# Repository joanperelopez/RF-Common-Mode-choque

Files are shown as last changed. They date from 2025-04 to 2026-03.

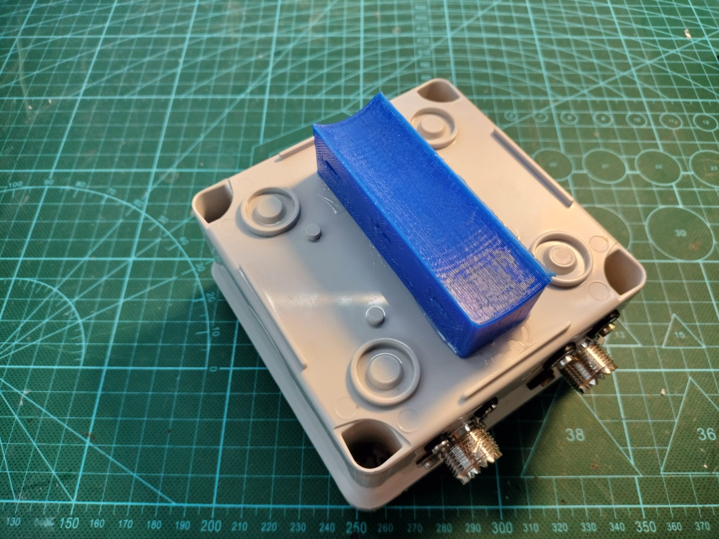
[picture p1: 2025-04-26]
IMAGES/WhatsApp Image 2025-04-26 at 18.15.16-2.jpeg

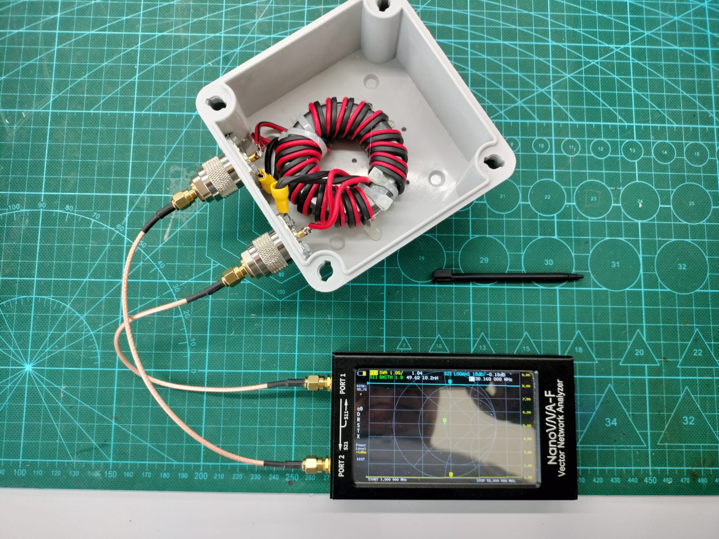
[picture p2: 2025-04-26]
IMAGES/WhatsApp Image 2025-04-26 at 18.15.17.jpeg

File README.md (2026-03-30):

# RF Common-Mode choque for outdoor use

This is the construction project of a common-mode filter designed to be installed on the mast, as close as possible to the antenna. It is housed inside an IP55-rated protective box with SO-239 connectors.
WhatsApp Image 2025-04-26 at 18 15 16
Common-mode choke. 10 turns of 2x1mm bifilar wire on each side of a 240-43 ferrite, as shown in the photograph.

WhatsApp Image 2025-04-26 at 18 15 17-2
Installation inside a weatherproof plastic box with IP55 protection. The connectors are SO-239, 50 Ohm.
Between the plastic box and the connectors, I applied white silicone.

The red wires at each end are soldered together to the center terminal of the corresponding SO-239 connector. The black wires at each end are also soldered together to the shell of the SO-239 connector.
Once all the connections were soldered, I applied a generous amount of white silicone to prevent moisture from reaching the connections.
I added rubber washers to the connector screws to prevent water from entering.

Secure the ferrite to the box using hot glue.

### Let’s see how it performs with the NanoVNA

WhatsApp Image 2025-04-26 at 18 15 15-2
The impedance is correctly maintained at 50 Ohms in the range of 1.8 MHz to 52 MHz.

WhatsApp Image 2025-04-26 at 18 15 15
The common-mode attenuation remains below -30 dBm. In the 20-meter band, it reaches -36 dBm.

WhatsApp Image 2025-04-26 at 18 15 17
The insertion loss is -0.1 dBm.

### We make the final touches
WhatsApp Image 2025-04-26 at 18 15 14
The completed choke with the placement of the informational label.

WhatsApp Image 2025-04-26 at 18 15 16-2
Installation of a bracket to allow it to be mounted on the antenna mast. It is attached to the box using a two-component adhesive. 
You can download it from the MECHANICAL folder.

WhatsApp Image 2025-04-26 at 18 15 14-2
Only three cable ties are needed for securing it to the antenna mast.

### RF choque version two
WhatsApp Image 2026-03-30 at 12 33 22
I've made another version of the RF choke, as I was experiencing some RF in the radio room. It consists of 14 turns of RG58 coaxial cable, as shown in the photo. Made with a toroidal core 240-31.

WhatsApp Image 2026-03-30 at 12 33 22 (1)
The impedance remains very stable: 49,9 Ohm at 100Khz. (ROE 1.0)  49,5 Ohm at 52 Mhz. (ROE 1.01)  47,6 Ohm at 100Mhz. (ROE 1.07).

The insertion loss are very low: 0dB at 100Khz.  0,23dB at 52Mhz.

WhatsApp Image 2026-03-30 at 12 33 23
It doesn't have much common-mode attenuation, but it's sufficient to eliminate the residual RF.
ATTENUATION:
-36 dB at 7Mhz.
-28 dB at 14Mhz.
-24 dB at 21Mhz.
-21 dB at 28Mhz.

WhatsApp Image 2026-03-30 at 12 51 59
Easy installed in the antenna switch

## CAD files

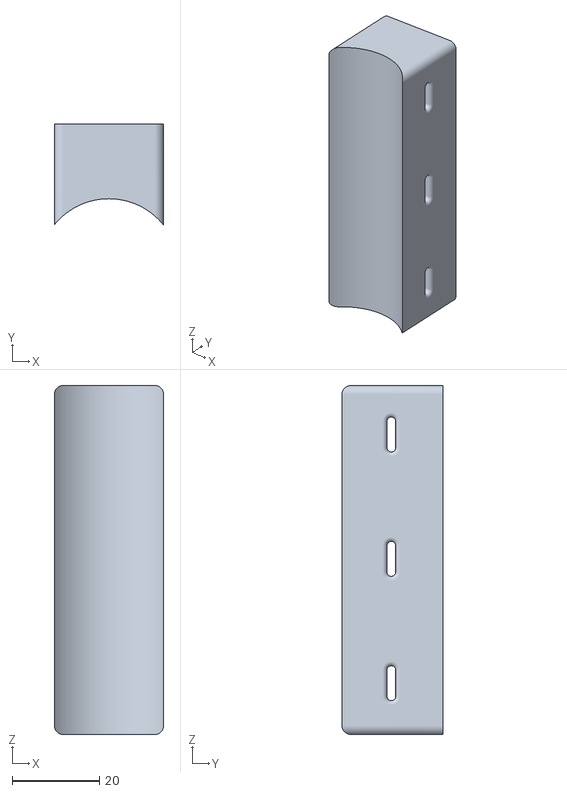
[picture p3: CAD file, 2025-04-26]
MECHANICAL/Soporte.stl
25.0 x 23.2 x 80.0

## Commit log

2026-03-30 Add image and installation note to README
    Added an image and installation note for the antenna switch.
2026-03-30 Update README with RF choke performance details
    Added information about insertion loss and clarified impedance details.
